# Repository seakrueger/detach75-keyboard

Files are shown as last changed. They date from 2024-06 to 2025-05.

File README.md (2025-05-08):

# detach75-keyboard
A 75% mechanical keyboard created for my high school PLTW capstone course. On top of being a standard mechanical keyboard, there is an integrated USB 2.0 hub with a second USB data line exposed internally. This allowed a 2.4 GHz USB receiver to be soldered on and connect to a wireless number pad for expanded functionality. 



## PCB
The design and layout of the PCB would not have been possible without this [series of articles](https://www.masterzen.fr/tag/#pcb) from Masterzen. Following his process, I adapted the matrix from a 60% layout to a 75% layout and integrated the USB 2.0 hub IC onto the USB D+/- lines. The PCB is relatively basic, being only two layers and missing several elements such as ground pours. The manufactured version of the PCB had two incorrectly placed capacitors that prevented the MCU from staying on and had to be removed; the included CAD files have been corrected. 



## Firmware
The keyboard uses the widely popular QMK firmware. QMK is the firmware of choice among keyboard enthusiasts as it is easily customizable with a rich set of features. Included is the configuration for the PCB's switch matrix as well as a basic setup of modifier keys.

To flash the PCB's MCU, first set up QMK following their guide [here](https://docs.qmk.fm/newbs_getting_started). Then, copy the contents of the Firmware directory into the QMK keyboard directory. Compile the firmware with `qmk compile -kb detach/75 -km default` and flash using QMK's [flashing guide](https://docs.qmk.fm/newbs_flashing). Use the reset push button on the underside of the PCB to initiate the ATmega bootloader; the MCU can be flashed via the USB-C port.

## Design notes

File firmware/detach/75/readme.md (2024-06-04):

# detach75

detach75

*A short description of the keyboard/project*

* Keyboard Maintainer: [Sean Krueger](https://github.com/Sean Krueger)
* Hardware Supported: *The PCBs, controllers supported*
* Hardware Availability: *Links to where you can find this hardware*

Make example for this keyboard (after setting up your build environment):

    make detach/75:default

Flashing example for this keyboard:

    make detach/75:default:flash

See the [build environment setup](https://docs.qmk.fm/#/getting_started_build_tools) and the [make instructions](https://docs.qmk.fm/#/getting_started_make_guide) for more information. Brand new to QMK? Start with our [Complete Newbs Guide](https://docs.qmk.fm/#/newbs).

## Bootloader

Enter the bootloader in 3 ways:

* **Bootmagic reset**: Hold down the key at (0,0) in the matrix (usually the top left key or Escape) and plug in the keyboard
* **Physical reset button**: Briefly press the button on the back of the PCB - some may have pads you must short instead
* **Keycode in layout**: Press the key mapped to `QK_BOOT` if it is available

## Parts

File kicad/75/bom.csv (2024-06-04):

Comment | Designator | Footprint | LCSC
10uF | C1,C2,C3,C7 | C_0805_2012Metric_Pad1.18x1.45mm_HandSolder | C95841
100uF | C14 | C_Elec_6.3x5.4 | C111600
22pF | C4,C5 | C_0805_2012Metric_Pad1.18x1.45mm_HandSolder | C1804
1uF | C6 | C_0805_2012Metric_Pad1.18x1.45mm_HandSolder | C116352
100nF | C8,C9,C10,C11,C12 | C_0805_2012Metric_Pad1.18x1.45mm_HandSolder | C346219
D | D1,D2,D3,D4,D5,D7,D8,D9,D10,D11,D12,D13,D14,D15,D16,D17,D18,D19,D20,D21,D22,D23,D24,D25,D26,D27,D28,D29,D30,D31,D32,D33,D34,D35,D36,D37,D38,D39,D40,D41,D42,D43,D44,D45,D46,D47,D48,D49,D50,D51,D52,D53,D54,D55,D56,D57,D58,D59,D61,D62,D63,D64,D65,D66,D67,D68,D69,D70,D71,D72,D76,D77,D78,D81,D85,D86,D87,D88,D89,D90 | D_SOD-123 | C77978
PRTR5V0U2X | D6 | SOT-143 | C2827688
500m | F1 | Fuse_1206_3216Metric_Pad1.42x1.75mm_HandSolder | C70069
USB_C_Receptacle_USB2.0_14P | J1 | USB_C_Receptacle_HRO_TYPE-C-31-M-12 | C165948
AVR-ISP-6 | J2 | random-keyboard-parts:Reset_Pretty-Mask
Conn_01x04 | J3 | Connector_JST:JST_SH_SM04B-SRSS-TB_1x04-1MP_P1.00mm_Horizontal
ESC | K000 | PCM_Switch_Keyboard_Hotswap_Kailh:SW_Hotswap_Kailh_MX_1.00u
F1 | K002 | PCM_Switch_Keyboard_Hotswap_Kailh:SW_Hotswap_Kailh_MX_1.00u
F2 | K003 | PCM_Switch_Keyboard_Hotswap_Kailh:SW_Hotswap_Kailh_MX_1.00u
F3 | K004 | PCM_Switch_Keyboard_Hotswap_Kailh:SW_Hotswap_Kailh_MX_1.00u
F4 | K005 | PCM_Switch_Keyboard_Hotswap_Kailh:SW_Hotswap_Kailh_MX_1.00u
F5 | K006 | PCM_Switch_Keyboard_Hotswap_Kailh:SW_Hotswap_Kailh_MX_1.00u
F6 | K007 | PCM_Switch_Keyboard_Hotswap_Kailh:SW_Hotswap_Kailh_MX_1.00u
F7 | K008 | PCM_Switch_Keyboard_Hotswap_Kailh:SW_Hotswap_Kailh_MX_1.00u
F8 | K009 | PCM_Switch_Keyboard_Hotswap_Kailh:SW_Hotswap_Kailh_MX_1.00u
F9 | K010 | PCM_Switch_Keyboard_Hotswap_Kailh:SW_Hotswap_Kailh_MX_1.00u
F10 | K011 | PCM_Switch_Keyboard_Hotswap_Kailh:SW_Hotswap_Kailh_MX_1.00u
F11 | K012 | PCM_Switch_Keyboard_Hotswap_Kailh:SW_Hotswap_Kailh_MX_1.00u
F12 | K013 | PCM_Switch_Keyboard_Hotswap_Kailh:SW_Hotswap_Kailh_MX_1.00u
F13 | K014 | PCM_Switch_Keyboard_Hotswap_Kailh:SW_Hotswap_Kailh_MX_1.00u
~ | K100 | PCM_Switch_Keyboard_Hotswap_Kailh:SW_Hotswap_Kailh_MX_1.00u
1 | K101 | PCM_Switch_Keyboard_Hotswap_Kailh:SW_Hotswap_Kailh_MX_1.00u
2 | K102 | PCM_Switch_Keyboard_Hotswap_Kailh:SW_Hotswap_Kailh_MX_1.00u
3 | K103 | PCM_Switch_Keyboard_Hotswap_Kailh:SW_Hotswap_Kailh_MX_1.00u
4 | K104 | PCM_Switch_Keyboard_Hotswap_Kailh:SW_Hotswap_Kailh_MX_1.00u
5 | K105 | PCM_Switch_Keyboard_Hotswap_Kailh:SW_Hotswap_Kailh_MX_1.00u
6 | K106 | PCM_Switch_Keyboard_Hotswap_Kailh:SW_Hotswap_Kailh_MX_1.00u
7 | K107 | PCM_Switch_Keyboard_Hotswap_Kailh:SW_Hotswap_Kailh_MX_1.00u
8 | K108 | PCM_Switch_Keyboard_Hotswap_Kailh:SW_Hotswap_Kailh_MX_1.00u
9 | K109 | PCM_Switch_Keyboard_Hotswap_Kailh:SW_Hotswap_Kailh_MX_1.00u
0 | K110 | PCM_Switch_Keyboard_Hotswap_Kailh:SW_Hotswap_Kailh_MX_1.00u
- | K111 | PCM_Switch_Keyboard_Hotswap_Kailh:SW_Hotswap_Kailh_MX_1.00u
= | K112 | PCM_Switch_Keyboard_Hotswap_Kailh:SW_Hotswap_Kailh_MX_1.00u
Backspace | K113 | PCM_Switch_Keyboard_Hotswap_Kailh:SW_Hotswap_Kailh_MX_2.00u
Insert | K114 | PCM_Switch_Keyboard_Hotswap_Kailh:SW_Hotswap_Kailh_MX_1.00u
Tab | K200 | PCM_Switch_Keyboard_Hotswap_Kailh:SW_Hotswap_Kailh_MX_1.50u
Q | K201 | PCM_Switch_Keyboard_Hotswap_Kailh:SW_Hotswap_Kailh_MX_1.00u
W | K202 | PCM_Switch_Keyboard_Hotswap_Kailh:SW_Hotswap_Kailh_MX_1.00u
E | K203 | PCM_Switch_Keyboard_Hotswap_Kailh:SW_Hotswap_Kailh_MX_1.00u
R | K204 | PCM_Switch_Keyboard_Hotswap_Kailh:SW_Hotswap_Kailh_MX_1.00u
T | K205 | PCM_Switch_Keyboard_Hotswap_Kailh:SW_Hotswap_Kailh_MX_1.00u
Y | K206 | PCM_Switch_Keyboard_Hotswap_Kailh:SW_Hotswap_Kailh_MX_1.00u
U | K207 | PCM_Switch_Keyboard_Hotswap_Kailh:SW_Hotswap_Kailh_MX_1.00u
I | K208 | PCM_Switch_Keyboard_Hotswap_Kailh:SW_Hotswap_Kailh_MX_1.00u
O | K209 | PCM_Switch_Keyboard_Hotswap_Kailh:SW_Hotswap_Kailh_MX_1.00u
P | K210 | PCM_Switch_Keyboard_Hotswap_Kailh:SW_Hotswap_Kailh_MX_1.00u
[ | K211 | PCM_Switch_Keyboard_Hotswap_Kailh:SW_Hotswap_Kailh_MX_1.00u
] | K212 | PCM_Switch_Keyboard_Hotswap_Kailh:SW_Hotswap_Kailh_MX_1.00u
\ | K213 | PCM_Switch_Keyboard_Hotswap_Kailh:SW_Hotswap_Kailh_MX_1.50u
Delete | K214 | PCM_Switch_Keyboard_Hotswap_Kailh:SW_Hotswap_Kailh_MX_1.00u
Caps Lock | K300 | PCM_Switch_Keyboard_Hotswap_Kailh:SW_Hotswap_Kailh_MX_1.75u
A | K301 | PCM_Switch_Keyboard_Hotswap_Kailh:SW_Hotswap_Kailh_MX_1.00u
S | K302 | PCM_Switch_Keyboard_Hotswap_Kailh:SW_Hotswap_Kailh_MX_1.00u
D | K303 | PCM_Switch_Keyboard_Hotswap_Kailh:SW_Hotswap_Kailh_MX_1.00u
F | K304 | PCM_Switch_Keyboard_Hotswap_Kailh:SW_Hotswap_Kailh_MX_1.00u
G | K305 | PCM_Switch_Keyboard_Hotswap_Kailh:SW_Hotswap_Kailh_MX_1.00u
H | K306 | PCM_Switch_Keyboard_Hotswap_Kailh:SW_Hotswap_Kailh_MX_1.00u
J | K307 | PCM_Switch_Keyboard_Hotswap_Kailh:SW_Hotswap_Kailh_MX_1.00u
K | K308 | PCM_Switch_Keyboard_Hotswap_Kailh:SW_Hotswap_Kailh_MX_1.00u
L | K309 | PCM_Switch_Keyboard_Hotswap_Kailh:SW_Hotswap_Kailh_MX_1.00u
; | K310 | PCM_Switch_Keyboard_Hotswap_Kailh:SW_Hotswap_Kailh_MX_1.00u
' | K311 | PCM_Switch_Keyboard_Hotswap_Kailh:SW_Hotswap_Kailh_MX_1.00u
Enter | K312 | PCM_Switch_Keyboard_Hotswap_Kailh:SW_Hotswap_Kailh_MX_2.25u
Left Shift | K400 | PCM_Switch_Keyboard_Hotswap_Kailh:SW_Hotswap_Kailh_MX_2.25u
Z | K401 | PCM_Switch_Keyboard_Hotswap_Kailh:SW_Hotswap_Kailh_MX_1.00u
X | K402 | PCM_Switch_Keyboard_Hotswap_Kailh:SW_Hotswap_Kailh_MX_1.00u
C | K403 | PCM_Switch_Keyboard_Hotswap_Kailh:SW_Hotswap_Kailh_MX_1.00u
V | K404 | PCM_Switch_Keyboard_Hotswap_Kailh:SW_Hotswap_Kailh_MX_1.00u
B | K405 | PCM_Switch_Keyboard_Hotswap_Kailh:SW_Hotswap_Kailh_MX_1.00u
N | K406 | PCM_Switch_Keyboard_Hotswap_Kailh:SW_Hotswap_Kailh_MX_1.00u
M | K407 | PCM_Switch_Keyboard_Hotswap_Kailh:SW_Hotswap_Kailh_MX_1.00u
, | K408 | PCM_Switch_Keyboard_Hotswap_Kailh:SW_Hotswap_Kailh_MX_1.00u
. | K409 | PCM_Switch_Keyboard_Hotswap_Kailh:SW_Hotswap_Kailh_MX_1.00u
/ | K410 | PCM_Switch_Keyboard_Hotswap_Kailh:SW_Hotswap_Kailh_MX_1.00u
Right Shift | K411 | PCM_Switch_Keyboard_Hotswap_Kailh:SW_Hotswap_Kailh_MX_1.75u
Up Arrow | K413 | PCM_Switch_Keyboard_Hotswap_Kailh:SW_Hotswap_Kailh_MX_1.00u
Left Ctrl | K500 | PCM_Switch_Keyboard_Hotswap_Kailh:SW_Hotswap_Kailh_MX_1.25u
Windows | K501 | PCM_Switch_Keyboard_Hotswap_Kailh:SW_Hotswap_Kailh_MX_1.25u
Left Alt | K502 | PCM_Switch_Keyboard_Hotswap_Kailh:SW_Hotswap_Kailh_MX_1.25u
Space | K505 | PCM_Switch_Keyboard_Hotswap_Kailh:SW_Hotswap_Kailh_MX_6.25u
Right Alt | K509 | PCM_Switch_Keyboard_Hotswap_Kailh:SW_Hotswap_Kailh_MX_1.00u
Fn | K510 | PCM_Switch_Keyboard_Hotswap_Kailh:SW_Hotswap_Kailh_MX_1.00u
Right Ctrl | K511 | PCM_Switch_Keyboard_Hotswap_Kailh:SW_Hotswap_Kailh_MX_1.00u
Left Arrow | K512 | PCM_Switch_Keyboard_Hotswap_Kailh:SW_Hotswap_Kailh_MX_1.00u
Down Arrow | K513 | PCM_Switch_Keyboard_Hotswap_Kailh:SW_Hotswap_Kailh_MX_1.00u
Right Arrow | K514 | PCM_Switch_Keyboard_Hotswap_Kailh:SW_Hotswap_Kailh_MX_1.00u
5.1k | R1,R2 | R_0805_2012Metric_Pad1.20x1.40mm_HandSolder | C27834
22 | R3,R4 | R_0805_2012Metric_Pad1.20x1.40mm_HandSolder | C17561
10k | R5,R6 | R_0805_2012Metric_Pad1.20x1.40mm_HandSolder | C17402
ATmega32U4-A | U1 | TQFP-44_10x10mm_P0.8mm | C44854
SL2.1A | U2 | SO16 | C6798314
~ | U3 | SW_SPST_SKQG_WithStem | C115351
Crystal_GND24_Small | Y1 | Crystal_SMD_3225-4Pin_3.2x2.5mm_HandSoldering | C255909

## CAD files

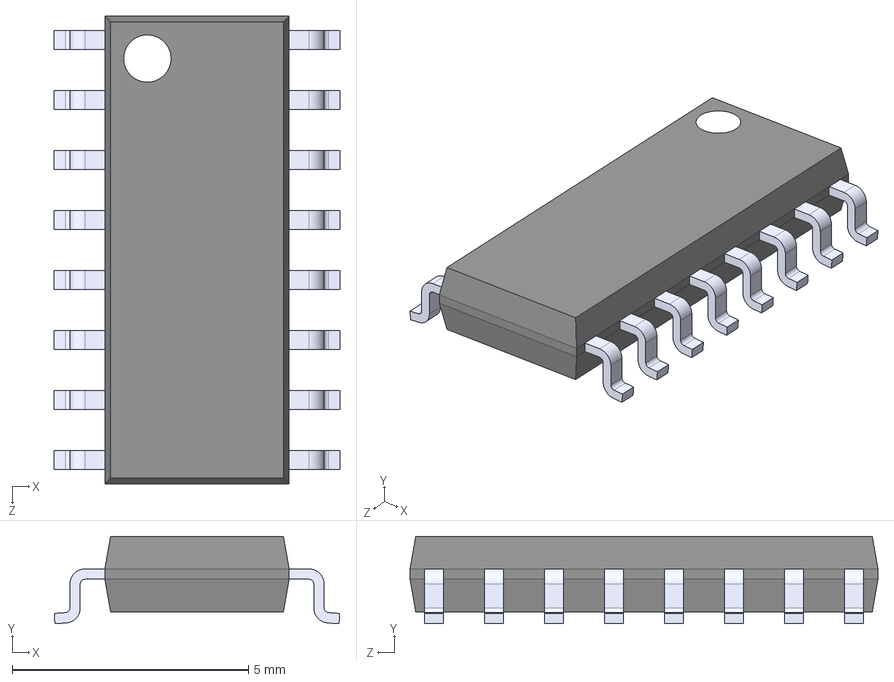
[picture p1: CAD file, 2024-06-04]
kicad/75/sl21a/SL2.1A.step
6.04 x 1.85 x 9.90 mm

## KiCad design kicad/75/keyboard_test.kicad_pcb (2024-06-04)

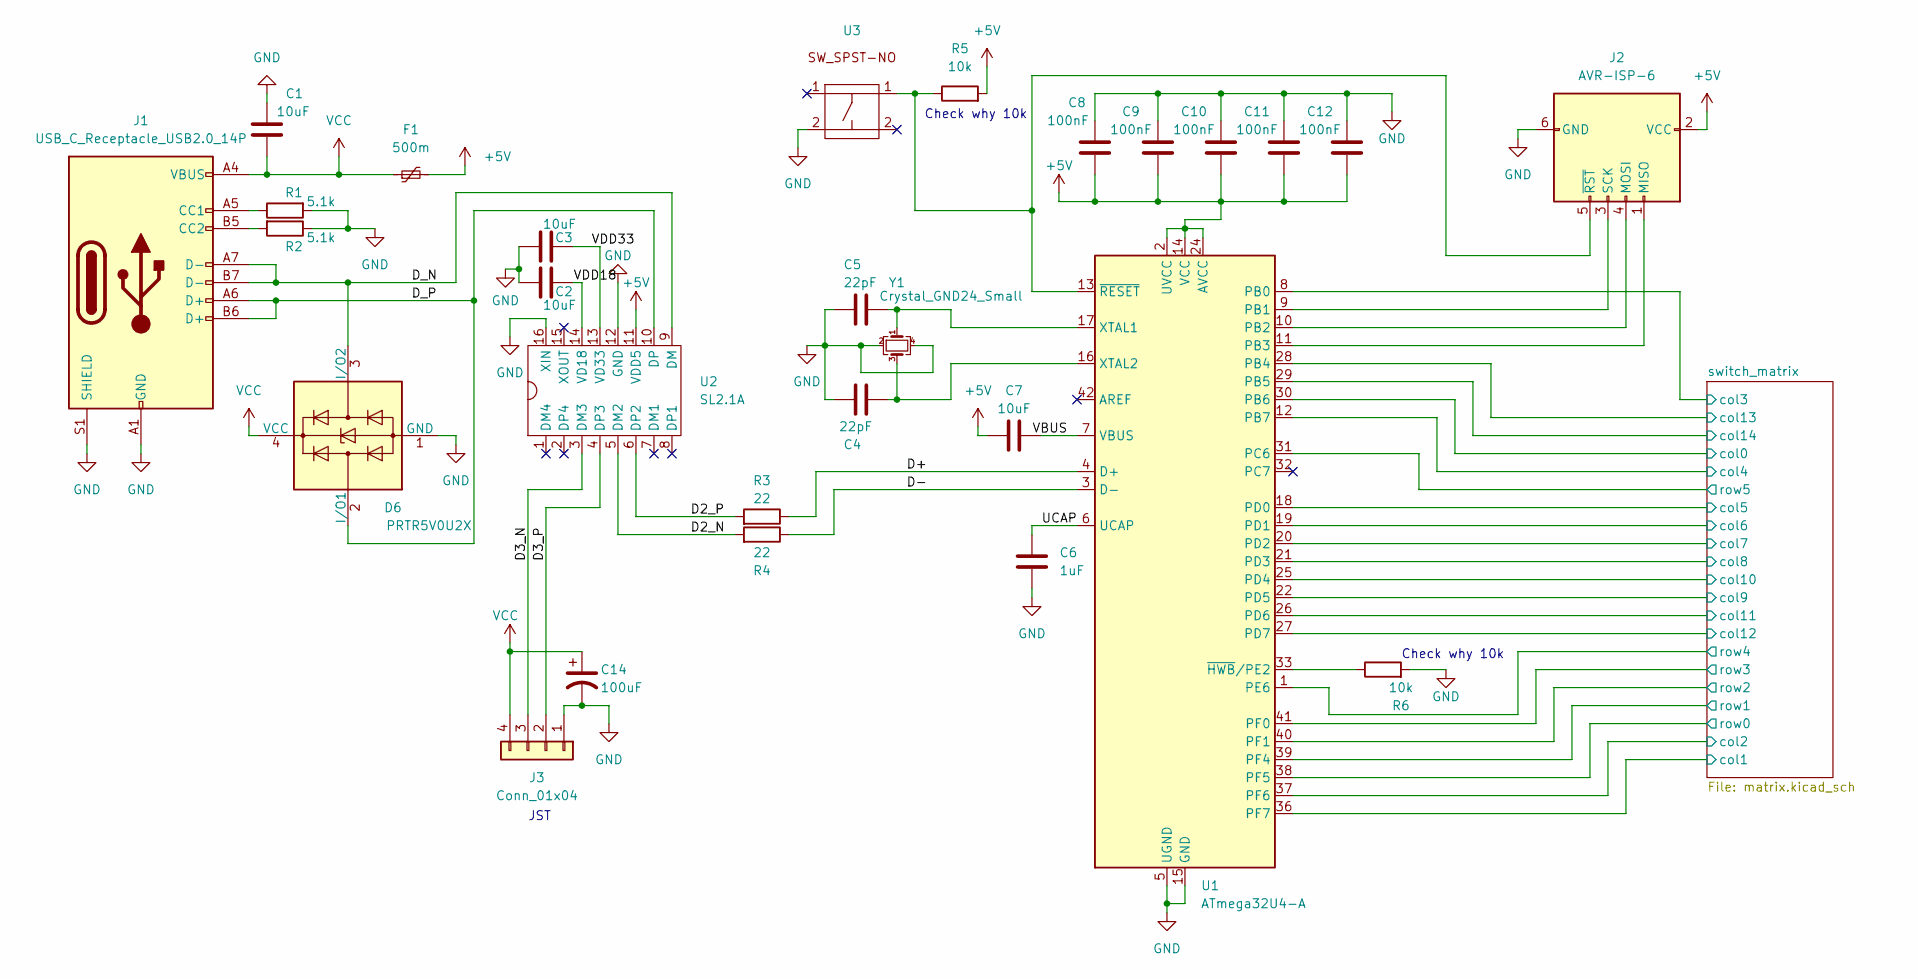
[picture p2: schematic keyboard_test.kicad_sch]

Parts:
C1, C2, C3, C7: 10uF; C_0805_2012Metric_Pad1.18x1.45mm_HandSolder; LCSC C95841
C4, C5: 22pF; C_0805_2012Metric_Pad1.18x1.45mm_HandSolder; LCSC C1804
C6: 1uF; C_0805_2012Metric_Pad1.18x1.45mm_HandSolder; LCSC C116352
C8, C9, C10, C11, C12: 100nF; C_0805_2012Metric_Pad1.18x1.45mm_HandSolder; LCSC C346219
C14: 100uF; C_Elec_6.3x5.4; LCSC C111600
D6: PRTR5V0U2X; SOT-143; LCSC C2827688
F1: 500m; Fuse_1206_3216Metric_Pad1.42x1.75mm_HandSolder; LCSC C70069
J1: USB_C_Receptacle_USB2.0_14P; USB_C_Receptacle_HRO_TYPE-C-31-M-12; LCSC C165948
J2: AVR-ISP-6; Reset_Pretty-Mask
J3: Conn_01x04; JST_SH_SM04B-SRSS-TB_1x04-1MP_P1.00mm_Horizontal
R1, R2: 5.1k; R_0805_2012Metric_Pad1.20x1.40mm_HandSolder; LCSC C27834
R3, R4: 22; R_0805_2012Metric_Pad1.20x1.40mm_HandSolder; LCSC C17561
R5, R6: 10k; R_0805_2012Metric_Pad1.20x1.40mm_HandSolder; LCSC C17402
U1: ATmega32U4-A; TQFP-44_10x10mm_P0.8mm; LCSC C44854
U2: SL2.1A; SO16; LCSC C6798314
U3: SW_SPST_SKQG_WithStem; LCSC C115351
Y1: Crystal_GND24_Small; Crystal_SMD_3225-4Pin_3.2x2.5mm_HandSoldering; LCSC C255909

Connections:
+5V: C7.1, C8.1, C9.1, C10.1, C11.1, C12.1, F1.2, J2.2 (VCC), R5.2, U1.2 (UVCC), U1.14 (VCC), U1.24 (AVCC), U1.34 (VCC), U1.44 (AVCC), U2.11 (VDD5)
/D2_N: R4.2, U2.5 (DM2)
/D2_P: R3.2, U2.6 (DP2)
/D3_N: J3.3, U2.3 (DM3)
/D3_P: J3.2, U2.4 (DP3)
/D+: R3.1, U1.4 (D+)
/D-: R4.1, U1.3 (D-)
/D_N: D6.3 (I/O2), J1.A7 (D-), J1.B7 (D-), U2.9 (DM)
/D_P: D6.2 (I/O1), J1.A6 (D+), J1.B6 (D+), U2.10 (DP)
/UCAP: C6.1, U1.6 (UCAP)
/VBUS: C7.2, U1.7 (VBUS)
/VDD18: C2.1, U2.14 (VD18)
/VDD33: C3.1, U2.13 (VD33)
/switch_matrix/col0: U1.30 (PB6); also elsewhere on the board
/switch_matrix/col1: U1.36 (PF7); also elsewhere on the board
/switch_matrix/col2: U1.37 (PF6); also elsewhere on the board
/switch_matrix/col3: U1.8 (PB0); also elsewhere on the board
/switch_matrix/col4: U1.12 (PB7); also elsewhere on the board
/switch_matrix/col5: U1.18 (PD0); also elsewhere on the board
/switch_matrix/col6: U1.19 (PD1); also elsewhere on the board
/switch_matrix/col7: U1.20 (PD2); also elsewhere on the board
/switch_matrix/col8: U1.21 (PD3); also elsewhere on the board
/switch_matrix/col9: U1.22 (PD5); also elsewhere on the board
/switch_matrix/col10: U1.25 (PD4); also elsewhere on the board
/switch_matrix/col11: U1.26 (PD6); also elsewhere on the board
/switch_matrix/col12: U1.27 (PD7); also elsewhere on the board
/switch_matrix/col13: U1.28 (PB4); also elsewhere on the board
/switch_matrix/col14: U1.29 (PB5); also elsewhere on the board
/switch_matrix/row0: U1.38 (PF5); also elsewhere on the board
/switch_matrix/row1: U1.39 (PF4); also elsewhere on the board
/switch_matrix/row2: U1.40 (PF1); also elsewhere on the board
/switch_matrix/row3: U1.41 (PF0); also elsewhere on the board
/switch_matrix/row4: U1.1 (PE6); also elsewhere on the board
/switch_matrix/row5: U1.31 (PC6); also elsewhere on the board
GND: C1.1, C2.2, C3.2, C4.2, C5.2, C6.2, C8.2, C9.2, C10.2, C11.2, C12.2, C14.2, D6.1 (GND), J1.A1 (GND), J1.A12 (GND), J1.B1 (GND), J1.B12 (GND), J1.S1 (SHIELD), J2.6 (GND), J3.1, R1.2, R2.1, R6.2, U1.5 (UGND), U1.15 (GND), U1.23 (GND), U1.35 (GND), U1.43 (GND), U2.12 (GND), U2.16 (XIN), U3.2, Y1.2, Y1.4
unnamed: J1.A5 (CC1), R1.1
unnamed: J1.B5 (CC2), R2.2
unnamed: J2.1 (MISO), U1.11 (PB3)
unnamed: J2.4 (MOSI), U1.10 (PB2)
unnamed: J2.3 (SCK), U1.9 (PB1)
unnamed: J2.5 (~RST), R5.1, U1.13 (~RESET), U3.1
unnamed: C5.1, U1.17 (XTAL1), Y1.1
unnamed: C4.1, U1.16 (XTAL2), Y1.3
unnamed: R6.1, U1.33 (~HWB/PE2)
VCC: C1.2, C14.1, D6.4 (VCC), F1.1, J1.A4 (VBUS), J1.A9 (VBUS), J1.B4 (VBUS), J1.B9 (VBUS), J3.4

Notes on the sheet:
Check why 10k
JST

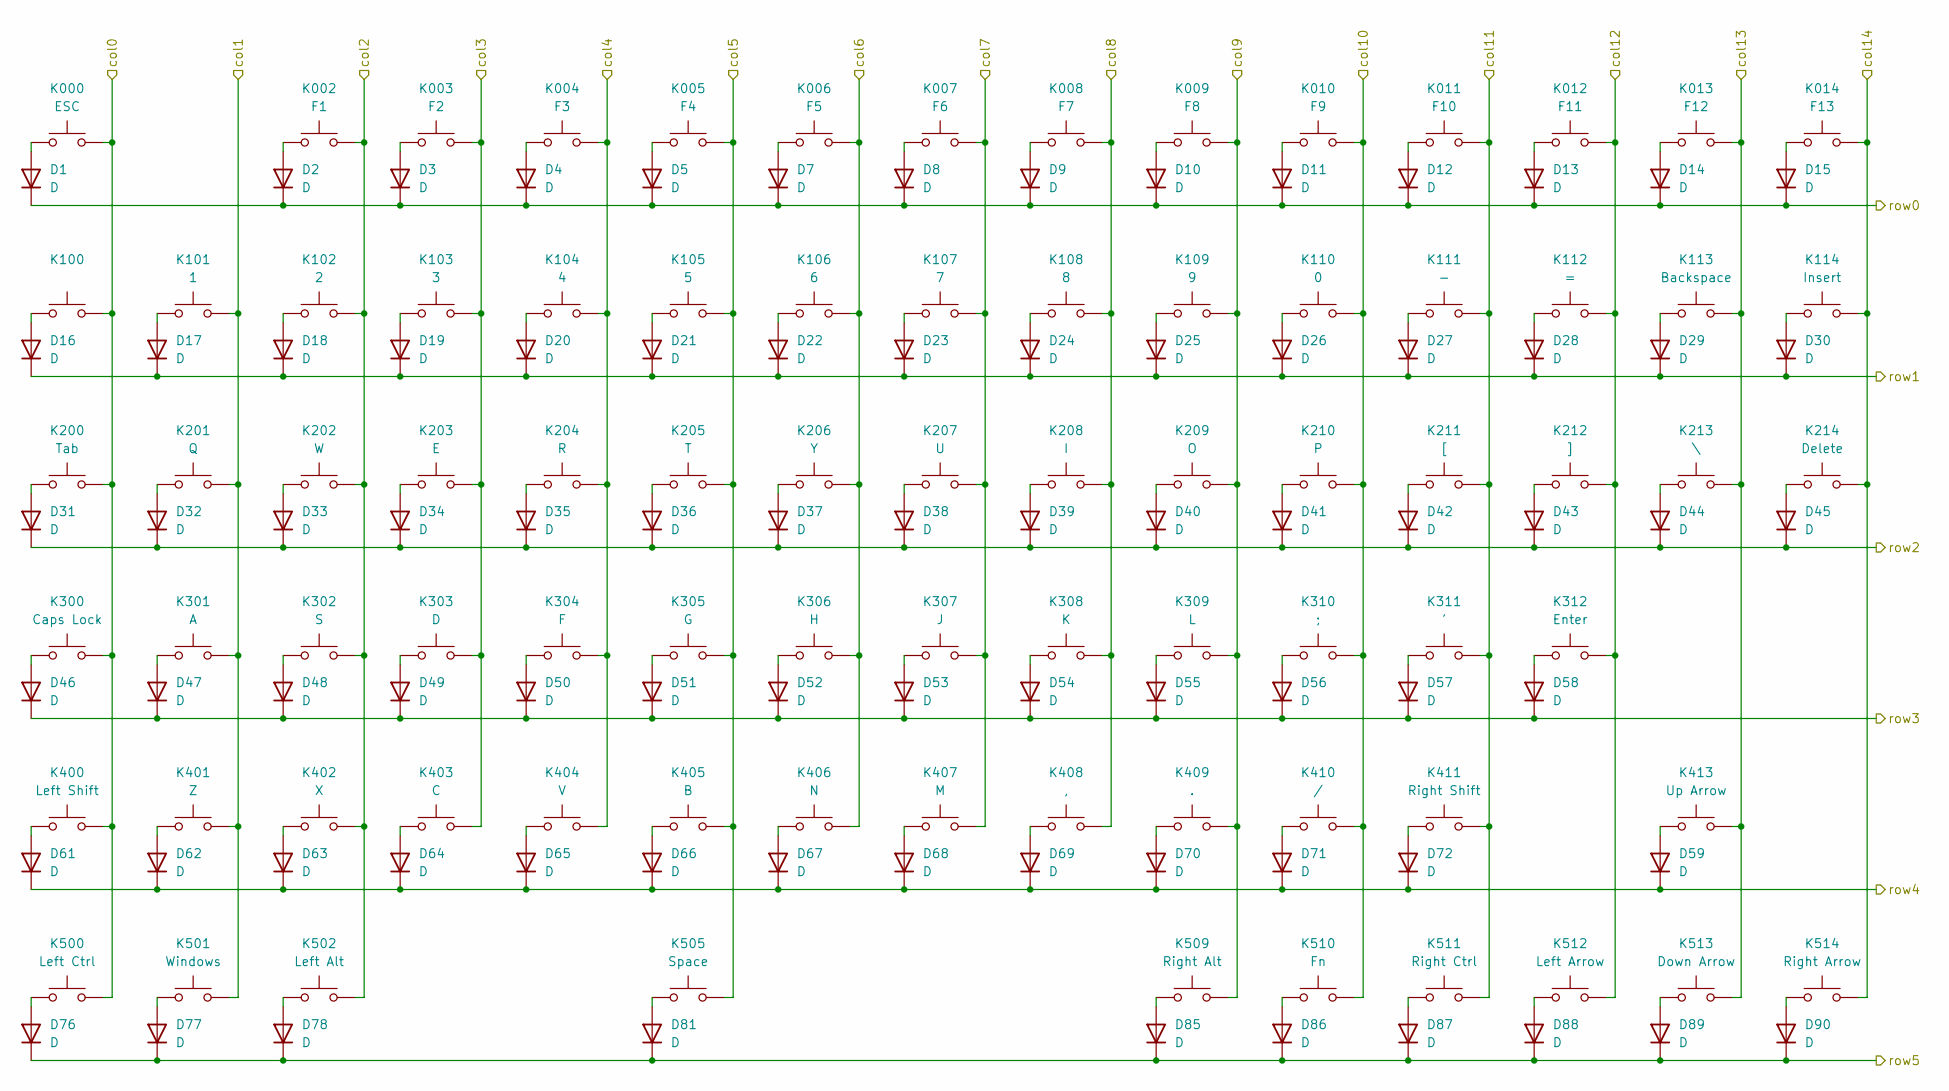
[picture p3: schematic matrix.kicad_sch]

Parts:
D1, D2, D3, D4, D5, D7, D8, D9, D10, D11, D12, D13, D14, D15, D16, D17, D18, D19, D20, D21, D22, D23, D24, D25, D26, D27, D28, D29, D30, D31, D32, D33, D34, D35, D36, D37, D38, D39, D40, D41, D42, D43, D44, D45, D46, D47, D48, D49, D50, D51, D52, D53, D54, D55, D56, D57, D58, D59, D61, D62, D63, D64, D65, D66, D67, D68, D69, D70, D71, D72, D76, D77, D78, D81, D85, D86, D87, D88, D89, D90: D; D_SOD-123; LCSC C77978
K000: ESC; SW_Hotswap_Kailh_MX_1.00u
K002: F1; SW_Hotswap_Kailh_MX_1.00u
K003: F2; SW_Hotswap_Kailh_MX_1.00u
K004: F3; SW_Hotswap_Kailh_MX_1.00u
K005: F4; SW_Hotswap_Kailh_MX_1.00u
K006: F5; SW_Hotswap_Kailh_MX_1.00u
K007: F6; SW_Hotswap_Kailh_MX_1.00u
K008: F7; SW_Hotswap_Kailh_MX_1.00u
K009: F8; SW_Hotswap_Kailh_MX_1.00u
K010: F9; SW_Hotswap_Kailh_MX_1.00u
K011: F10; SW_Hotswap_Kailh_MX_1.00u
K012: F11; SW_Hotswap_Kailh_MX_1.00u
K013: F12; SW_Hotswap_Kailh_MX_1.00u
K014: F13; SW_Hotswap_Kailh_MX_1.00u
K100: SW_Hotswap_Kailh_MX_1.00u
K101: 1; SW_Hotswap_Kailh_MX_1.00u
K102: 2; SW_Hotswap_Kailh_MX_1.00u
K103: 3; SW_Hotswap_Kailh_MX_1.00u
K104: 4; SW_Hotswap_Kailh_MX_1.00u
K105: 5; SW_Hotswap_Kailh_MX_1.00u
K106: 6; SW_Hotswap_Kailh_MX_1.00u
K107: 7; SW_Hotswap_Kailh_MX_1.00u
K108: 8; SW_Hotswap_Kailh_MX_1.00u
K109: 9; SW_Hotswap_Kailh_MX_1.00u
K110: 0; SW_Hotswap_Kailh_MX_1.00u
K111: -; SW_Hotswap_Kailh_MX_1.00u
K112: =; SW_Hotswap_Kailh_MX_1.00u
K113: Backspace; SW_Hotswap_Kailh_MX_2.00u
K114: Insert; SW_Hotswap_Kailh_MX_1.00u
K200: Tab; SW_Hotswap_Kailh_MX_1.50u
K201: Q; SW_Hotswap_Kailh_MX_1.00u
K202: W; SW_Hotswap_Kailh_MX_1.00u
K203: E; SW_Hotswap_Kailh_MX_1.00u
K204: R; SW_Hotswap_Kailh_MX_1.00u
K205: T; SW_Hotswap_Kailh_MX_1.00u
K206: Y; SW_Hotswap_Kailh_MX_1.00u
K207: U; SW_Hotswap_Kailh_MX_1.00u
K208: I; SW_Hotswap_Kailh_MX_1.00u
K209: O; SW_Hotswap_Kailh_MX_1.00u
K210: P; SW_Hotswap_Kailh_MX_1.00u
K211: [; SW_Hotswap_Kailh_MX_1.00u
K212: ]; SW_Hotswap_Kailh_MX_1.00u
K213: \; SW_Hotswap_Kailh_MX_1.50u
K214: Delete; SW_Hotswap_Kailh_MX_1.00u
K300: Caps Lock; SW_Hotswap_Kailh_MX_1.75u
K301: A; SW_Hotswap_Kailh_MX_1.00u
K302: S; SW_Hotswap_Kailh_MX_1.00u
K303: D; SW_Hotswap_Kailh_MX_1.00u
K304: F; SW_Hotswap_Kailh_MX_1.00u
K305: G; SW_Hotswap_Kailh_MX_1.00u
K306: H; SW_Hotswap_Kailh_MX_1.00u
K307: J; SW_Hotswap_Kailh_MX_1.00u
K308: K; SW_Hotswap_Kailh_MX_1.00u
K309: L; SW_Hotswap_Kailh_MX_1.00u
K310: ;; SW_Hotswap_Kailh_MX_1.00u
K311: '; SW_Hotswap_Kailh_MX_1.00u
K312: Enter; SW_Hotswap_Kailh_MX_2.25u
K400: Left Shift; SW_Hotswap_Kailh_MX_2.25u
K401: Z; SW_Hotswap_Kailh_MX_1.00u
K402: X; SW_Hotswap_Kailh_MX_1.00u
K403: C; SW_Hotswap_Kailh_MX_1.00u
K404: V; SW_Hotswap_Kailh_MX_1.00u
K405: B; SW_Hotswap_Kailh_MX_1.00u
K406: N; SW_Hotswap_Kailh_MX_1.00u
K407: M; SW_Hotswap_Kailh_MX_1.00u
K408: ,; SW_Hotswap_Kailh_MX_1.00u
K409: .; SW_Hotswap_Kailh_MX_1.00u
K410: /; SW_Hotswap_Kailh_MX_1.00u
K411: Right Shift; SW_Hotswap_Kailh_MX_1.75u
K413: Up Arrow; SW_Hotswap_Kailh_MX_1.00u
K500: Left Ctrl; SW_Hotswap_Kailh_MX_1.25u
K501: Windows; SW_Hotswap_Kailh_MX_1.25u
K502: Left Alt; SW_Hotswap_Kailh_MX_1.25u
K505: Space; SW_Hotswap_Kailh_MX_6.25u
K509: Right Alt; SW_Hotswap_Kailh_MX_1.00u
K510: Fn; SW_Hotswap_Kailh_MX_1.00u
K511: Right Ctrl; SW_Hotswap_Kailh_MX_1.00u
K512: Left Arrow; SW_Hotswap_Kailh_MX_1.00u
K513: Down Arrow; SW_Hotswap_Kailh_MX_1.00u
K514: Right Arrow; SW_Hotswap_Kailh_MX_1.00u

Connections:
/switch_matrix/col0: K000.2, K100.2, K200.2, K300.2, K400.2, K500.2; also elsewhere on the board
/switch_matrix/col1: K101.2, K201.2, K301.2, K401.2, K501.2; also elsewhere on the board
/switch_matrix/col2: K002.2, K102.2, K202.2, K302.2, K402.2, K502.2; also elsewhere on the board
/switch_matrix/col3: K003.2, K103.2, K203.2, K303.2, K403.2; also elsewhere on the board
/switch_matrix/col4: K004.2, K104.2, K204.2, K304.2, K404.2; also elsewhere on the board
/switch_matrix/col5: K005.2, K105.2, K205.2, K305.2, K405.2, K505.2; also elsewhere on the board
/switch_matrix/col6: K006.2, K106.2, K206.2, K306.2, K406.2; also elsewhere on the board
/switch_matrix/col7: K007.2, K107.2, K207.2, K307.2, K407.2; also elsewhere on the board
/switch_matrix/col8: K008.2, K108.2, K208.2, K308.2, K408.2; also elsewhere on the board
/switch_matrix/col9: K009.2, K109.2, K209.2, K309.2, K409.2, K509.2; also elsewhere on the board
/switch_matrix/col10: K010.2, K110.2, K210.2, K310.2, K410.2, K510.2; also elsewhere on the board
/switch_matrix/col11: K011.2, K111.2, K211.2, K311.2, K411.2, K511.2; also elsewhere on the board
/switch_matrix/col12: K012.2, K112.2, K212.2, K312.2, K512.2; also elsewhere on the board
/switch_matrix/col13: K013.2, K113.2, K213.2, K413.2, K513.2; also elsewhere on the board
/switch_matrix/col14: K014.2, K114.2, K214.2, K514.2; also elsewhere on the board
/switch_matrix/row0: D1.1 (K), D2.1 (K), D3.1 (K), D4.1 (K), D5.1 (K), D7.1 (K), D8.1 (K), D9.1 (K), D10.1 (K), D11.1 (K), D12.1 (K), D13.1 (K), D14.1 (K), D15.1 (K); also elsewhere on the board
/switch_matrix/row1: D16.1 (K), D17.1 (K), D18.1 (K), D19.1 (K), D20.1 (K), D21.1 (K), D22.1 (K), D23.1 (K), D24.1 (K), D25.1 (K), D26.1 (K), D27.1 (K), D28.1 (K), D29.1 (K), D30.1 (K); also elsewhere on the board
/switch_matrix/row2: D31.1 (K), D32.1 (K), D33.1 (K), D34.1 (K), D35.1 (K), D36.1 (K), D37.1 (K), D38.1 (K), D39.1 (K), D40.1 (K), D41.1 (K), D42.1 (K), D43.1 (K), D44.1 (K), D45.1 (K); also elsewhere on the board
/switch_matrix/row3: D46.1 (K), D47.1 (K), D48.1 (K), D49.1 (K), D50.1 (K), D51.1 (K), D52.1 (K), D53.1 (K), D54.1 (K), D55.1 (K), D56.1 (K), D57.1 (K), D58.1 (K); also elsewhere on the board
/switch_matrix/row4: D59.1 (K), D61.1 (K), D62.1 (K), D63.1 (K), D64.1 (K), D65.1 (K), D66.1 (K), D67.1 (K), D68.1 (K), D69.1 (K), D70.1 (K), D71.1 (K), D72.1 (K); also elsewhere on the board
/switch_matrix/row5: D76.1 (K), D77.1 (K), D78.1 (K), D81.1 (K), D85.1 (K), D86.1 (K), D87.1 (K), D88.1 (K), D89.1 (K), D90.1 (K); also elsewhere on the board
unnamed: D1.2 (A), K000.1
unnamed: D2.2 (A), K002.1
unnamed: D3.2 (A), K003.1
unnamed: D4.2 (A), K004.1
unnamed: D5.2 (A), K005.1
unnamed: D7.2 (A), K006.1
unnamed: D8.2 (A), K007.1
unnamed: D9.2 (A), K008.1
unnamed: D10.2 (A), K009.1
unnamed: D11.2 (A), K010.1
unnamed: D12.2 (A), K011.1
unnamed: D13.2 (A), K012.1
unnamed: D14.2 (A), K013.1
unnamed: D15.2 (A), K014.1
unnamed: D16.2 (A), K100.1
unnamed: D17.2 (A), K101.1
unnamed: D18.2 (A), K102.1
unnamed: D19.2 (A), K103.1
unnamed: D20.2 (A), K104.1
unnamed: D21.2 (A), K105.1
unnamed: D22.2 (A), K106.1
unnamed: D23.2 (A), K107.1
unnamed: D24.2 (A), K108.1
unnamed: D25.2 (A), K109.1
unnamed: D26.2 (A), K110.1
unnamed: D27.2 (A), K111.1
unnamed: D28.2 (A), K112.1
unnamed: D29.2 (A), K113.1
unnamed: D30.2 (A), K114.1
unnamed: D31.2 (A), K200.1
unnamed: D32.2 (A), K201.1
unnamed: D33.2 (A), K202.1
unnamed: D34.2 (A), K203.1
unnamed: D35.2 (A), K204.1
unnamed: D36.2 (A), K205.1
unnamed: D37.2 (A), K206.1
unnamed: D38.2 (A), K207.1
unnamed: D39.2 (A), K208.1
unnamed: D40.2 (A), K209.1
unnamed: D41.2 (A), K210.1
unnamed: D42.2 (A), K211.1
unnamed: D43.2 (A), K212.1
unnamed: D44.2 (A), K213.1
unnamed: D45.2 (A), K214.1
unnamed: D46.2 (A), K300.1
unnamed: D47.2 (A), K301.1
unnamed: D48.2 (A), K302.1
unnamed: D49.2 (A), K303.1
unnamed: D50.2 (A), K304.1
unnamed: D51.2 (A), K305.1
unnamed: D52.2 (A), K306.1
unnamed: D53.2 (A), K307.1
unnamed: D54.2 (A), K308.1
unnamed: D55.2 (A), K309.1
unnamed: D56.2 (A), K310.1
unnamed: D57.2 (A), K311.1
unnamed: D58.2 (A), K312.1
unnamed: D59.2 (A), K413.1
unnamed: D61.2 (A), K400.1
unnamed: D62.2 (A), K401.1
unnamed: D63.2 (A), K402.1
unnamed: D64.2 (A), K403.1
unnamed: D65.2 (A), K404.1
unnamed: D66.2 (A), K405.1
unnamed: D67.2 (A), K406.1
unnamed: D68.2 (A), K407.1
unnamed: D69.2 (A), K408.1
unnamed: D70.2 (A), K409.1
unnamed: D71.2 (A), K410.1
unnamed: D72.2 (A), K411.1
unnamed: D76.2 (A), K500.1
unnamed: D77.2 (A), K501.1
unnamed: D78.2 (A), K502.1
unnamed: D81.2 (A), K505.1
unnamed: D85.2 (A), K509.1
unnamed: D86.2 (A), K510.1
unnamed: D87.2 (A), K511.1
unnamed: D88.2 (A), K512.1
unnamed: D89.2 (A), K513.1
unnamed: D90.2 (A), K514.1

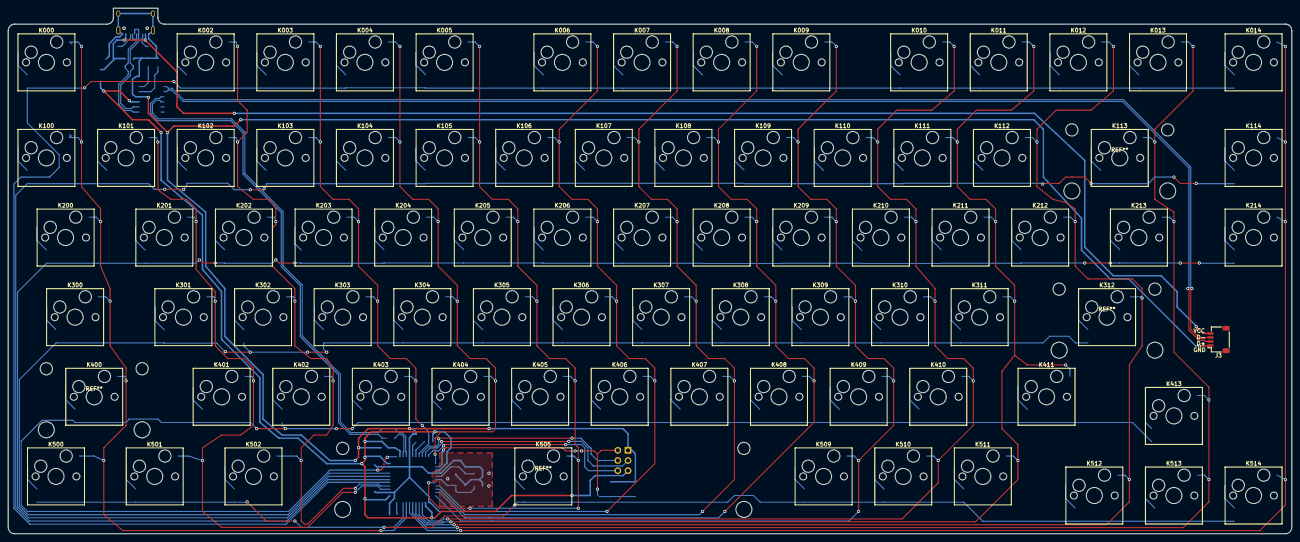
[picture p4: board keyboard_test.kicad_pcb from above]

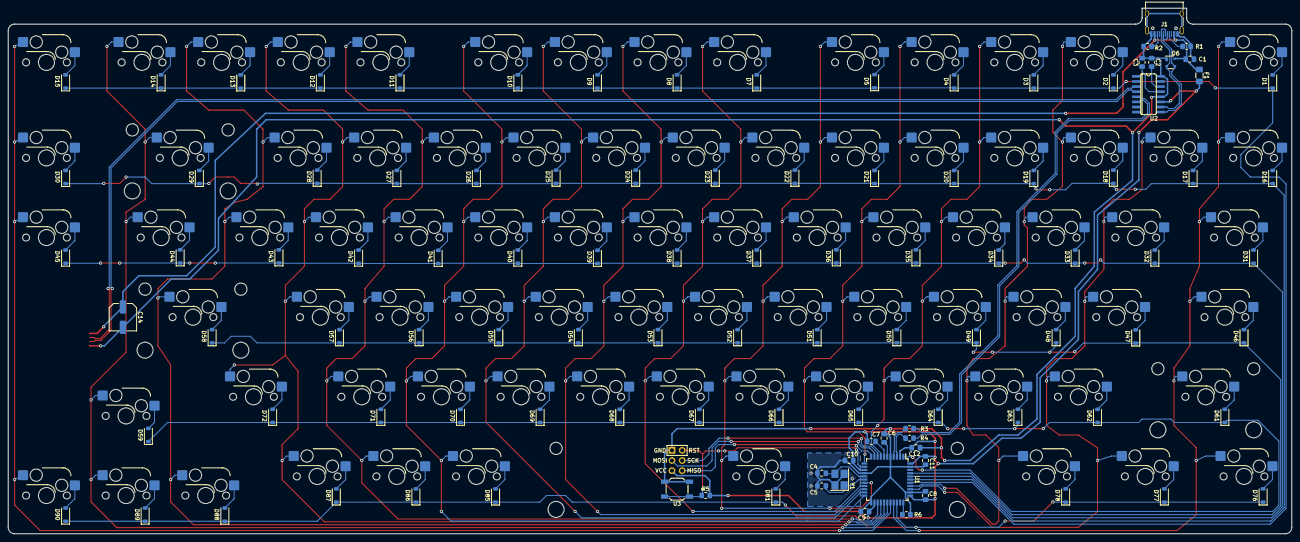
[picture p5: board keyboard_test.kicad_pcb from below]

Board: 2 copper layers, 319.9 x 131.0 mm, 188 parts (107 on the bottom side), 125 nets.
